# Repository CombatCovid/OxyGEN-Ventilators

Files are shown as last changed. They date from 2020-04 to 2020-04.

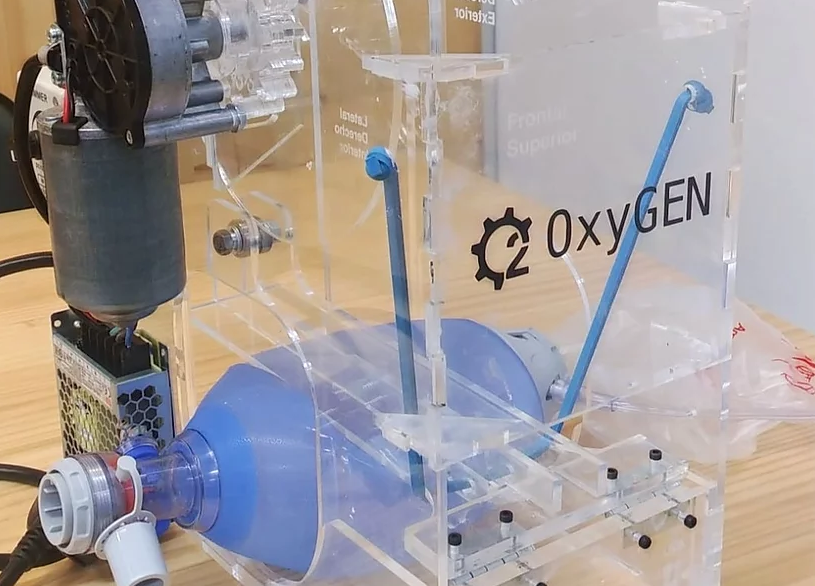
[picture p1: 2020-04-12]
summary.png

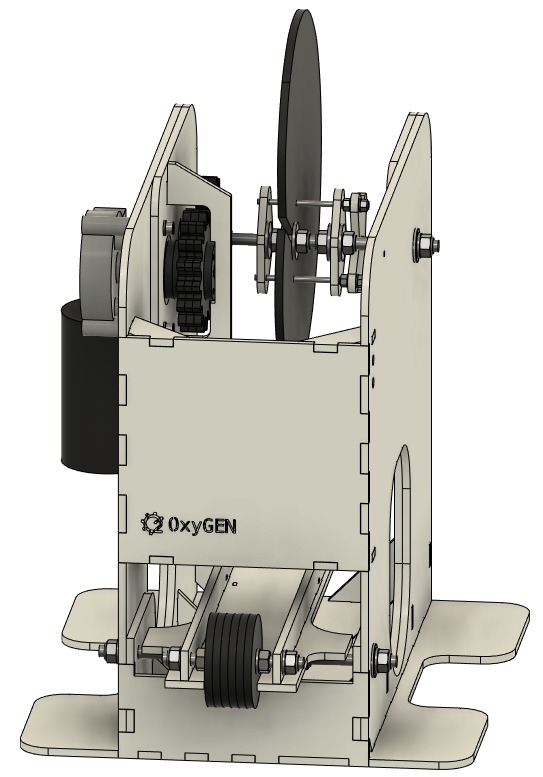
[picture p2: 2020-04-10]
docs/img/5 mm/4b5abb1e-1ea3-4c3a-8013-bc336fb86296.jpeg

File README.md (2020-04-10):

---
title: Title of the project
description: > 
    Put here a description of what the hardware does
keywords:
  - covid-19
  - medical equipment
project-link: https://e-vent.mit.edu/
made: true
made-independently: false
license:
  hardware: Put the license
okh-manifest-version: 1.0.0
date-updated: yyyy-mm-dd
manifest-author:
  name: author
  affiliation: MIT
contributors:
  - A name
  - Another name
sub-parts:
  - undefined
  - undefined
---
# Steps to start documenting the equipment/design you found and chose 
[See this documentation example](https://github.com/CombatCovid/medical-shields-for-3d-printing). You can also download it to see the final result.
1. Download or clone this template to start documenting easily
2. Fill in the source files like STLS, CAD, etc inside

3. Use this one template to create new designs documentation
- Inside docs write down a simple README in language of choice.
- Put in the README.md the reference whre you got the source from to follow up.
- Write down steps to replicate if necessesary as well as guides in sequence.
If this part becomes difficult ask for help here in the [`#how-to-document-designs` channel ](https://discord.gg/QrAyWF)

# Pasos para comenzar a documentar el equipo / diseño que encontró y eligió
[Vea este ejemplo de documentación](https://github.com/CombatCovid/medical-shields-for-3d-printing). Puede tambien descargar este ejemplo.
1. Descargue o clone esta plantilla para comenzar a documentar fácilmente
2. Complete los archivos de origen como STLS, CAD, etc. dentro

3. Utilice esta plantilla para crear documentación de nuevos diseños.
- Los documentos internos escriben un archivo README simple en el idioma de su elección.
- Ponga en README.md la referencia de donde obtuvo la fuente para hacer el seguimiento.
- Escriba los pasos para replicar si es necesario, así como las guías en secuencia.
Si esta parte se vuelve difícil, solicite ayuda aquí en el canal [`# how-to-document-designs`] (https://discord.gg/QrAyWF)

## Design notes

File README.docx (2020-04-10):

title: Emergency ventilator for COVID-19 crisis: OxyGEN-M

description: >

OxyGEN is an emergency device designed to be built by anyone around the world. However, at planetary scales, the availability of tools, materials and industrial facilities varies from place to place.

There are 2 different versions of OxyGEN. The maker version "OxyGEN-M"

and the industrial version "OxyGEN-IP".

OxyGEN-M is designed for makers and can be built using common tools and no special machinery or materials are needed.

keywords:

- covid-19

- medical equipment

- emergency ventilator

- OxyGEN

project-link: https://www.oxygen.protofy.xyz/

made: true

made-independently: false

license:

hardware: Put the license

okh-manifest-version: 1.0.0

date-updated: 2020-04-08

manifest-author:

name: Ramon Turró

affiliation: Protofy.xyz

contributors:

- undefined

sub-parts:

- undefined

- undefined

Location:

Barcelona

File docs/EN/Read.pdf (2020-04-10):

OxyGEN is an emergency device for the COVID-19 health crisis. OxyGEN is an open hardware prototype that has been collaboratively developed by a group of engineers led by Barcelona based company, PROTOFY.xyz. Initiated March 2020.
Web: https://www.oxygen.protofy.xyz/

The files that you’ll find inside this folder are to make the wooden version of the device when you don't have a laser or Cnc, although the plans also include a Dxf file to be used in a Cnc.
I’ve used hard birch plywood, although the best option is to use a hypoallergenic material such as methacrylate or Pvc. You could also use chipboard or Mdf with melamine on both sides, or varnishing the wood. You should use hard plywood or hard wood to make the gears.
If you install an electronic speed control, you can avoid doing the gears. You can also modify the ratio between the gears to adapt them to the revolutions of your Wiper Motor.

If you have any questions please contact me by email: info@paoson.com

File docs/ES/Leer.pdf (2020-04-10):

OxyGEN es un dispositivo de emergencia para la crisis sanitaria del COVID-19, Se trata de un prototipo de hardware abierto desarrollado por un grupo de ingenieros liderado por la empresa Barcelonesa Protofy.xyz. iniciado en Marzo 2020.
Web: https://www.oxygen.protofy.xyz/?lang=es

Los documentos que encontrarás en esta carpeta son los archivos para poder fabricar la version en madera del dispositivo. La idea es poder fabricar el dispositivo con herramienta manuales, sin una laser o Cnc, aunque los planos incluyen archivos Dxf para poder usar en un pantógrafo.
Aunque he usado contrachapado duro de abedul, lo ideal sería usar un material antiséptico y no madera, como metacrilato o Pvc. Como opción se podría usar tablero aglomerado o Mdf con melamina por ambas caras y cantear, o barnizar la madera. Los engranajes siempre con contrachapado duro o madera dura.
El motor podría ir directo y evitar los engranajes si se regula la velocidad de giro de forma electronica. También se puede modificar el ratio entre los engranajes para adaptarlos a las revoluciones de tu motor.

Si tienes alguna duda puedes contactarme por email: info@paoson.com

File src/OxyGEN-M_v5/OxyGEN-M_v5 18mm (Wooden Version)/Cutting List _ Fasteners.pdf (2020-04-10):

# Cutting List / Fasteners

Lateral Side 1 | 353 x 340 x 18mm | 18mm Hard Plywood
Lateral Side 2 | 353 x 340 x 18mm | 18mm Hard Plywood
Base | 340 x 142 x 18mm | 18mm Hard Plywood
Base Planca | 393 x 84 x 18mm | 18mm Hard Plywood
Lateral Palanca - | 293 x 52 x 18mm(x2) | 18mm Hard Plywood
Trasera Back 1 | 142x 35 x 18mm | 18mm Hard Plywood
Trasera Back 2 | 150 x 142 x 18mm | 18mm Hard Plywood
Sujeta Leva 1 | 70 x 50 x 18mm | 18mm Hard Plywood
Sujeta Leva 2 | 70 x 50 x 18mm | 18mm Hard Plywood
Engranaje Gear | 100 x 100 x 18mm | 18mm Hard Plywood
Engranaje Motor Gear | 100 x 100 x 18mm | 18mm Hard Plywood
Engranaje Motor Gear 2 | 37 x 37 x 18mm | 18mm Hard Plywood
Ejes | 50 x 25 x 18mm(x2) | 18mm Hard Plywood
Cam Leva 1 | 220 x 210 x 9mm | 9mm Hard Plywood
Cam Leva 1 | 250 x 230 x 9mm | 9mm Hard Plywood
Cam Leva 1 | 270 x 245 x 9mm | 9mm Hard Plywood
Cam Leva 1 | 300 x 270 x 9mm | 9mm Hard Plywood

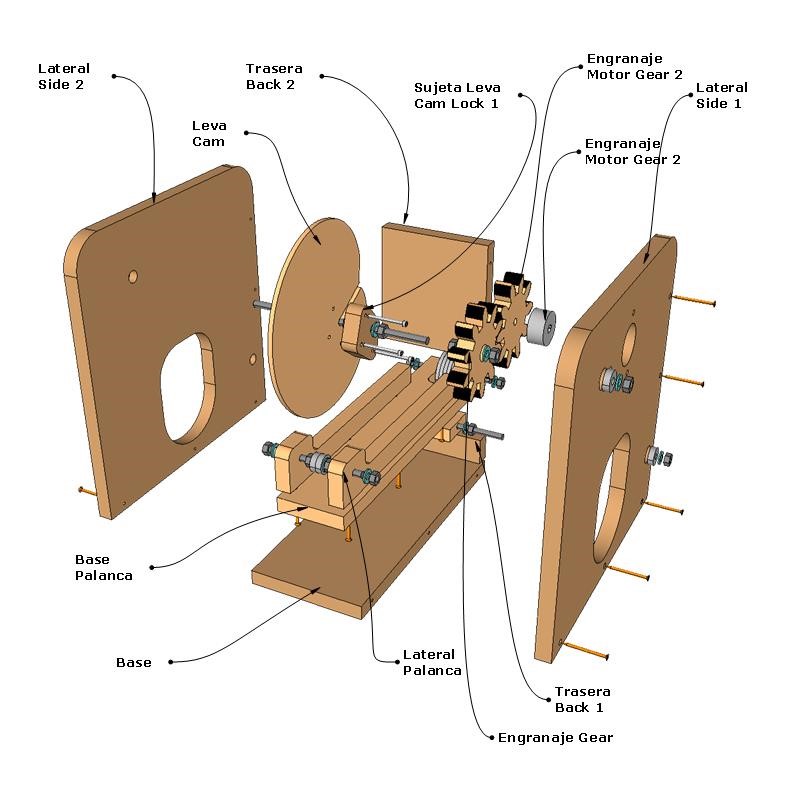
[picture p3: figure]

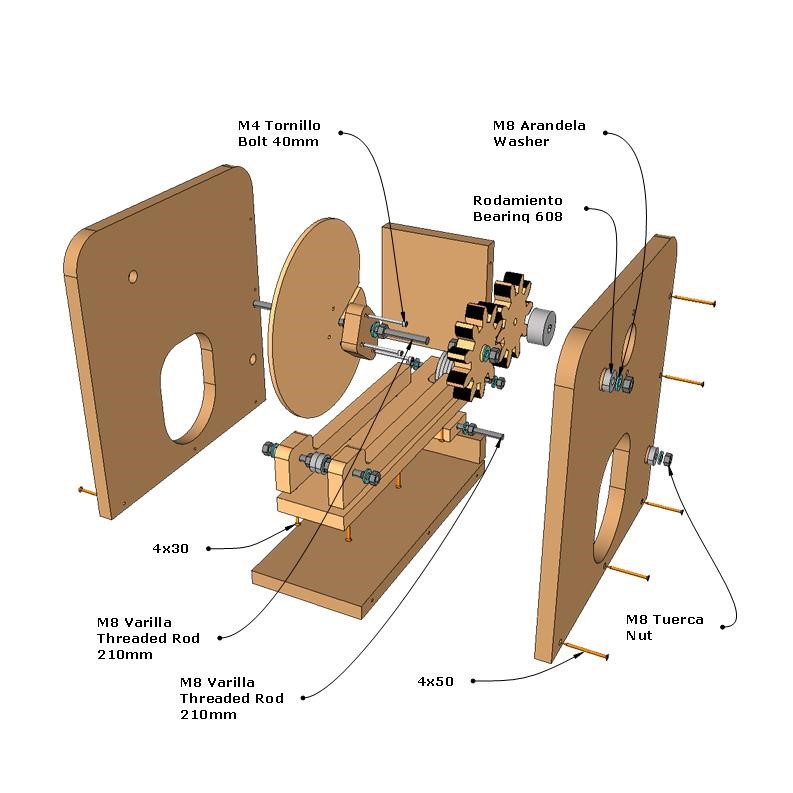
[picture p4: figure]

Allen Socket Head Screw: (https://www.paoson.com/forum/viewtopic.php?f=22&t=137)
3x M4 40mm

Threaded Rod/Varilla Roscada: (https://www.paoson.com/forum/viewtopic.php?f=22&t=892)
2x M8 210mm

Loking Nuts/Tuercas Autoblocantes: (https://www.paoson.com/forum/viewtopic.php?f=22&t=137) 16x M8

Washers / Arandelas: (https://www.paoson.com/forum/viewtopic.php?f=22&t=137)
16x M8 16mm Outer Diameter

Wood Screw: (https://www.paoson.com/forum/viewtopic.php?f=22&t=137)
10x 4x30
12x 4x50

1x Wiper Motor / Motor Limpiaparabrisas 6x 608 Bearings /Rodamientos

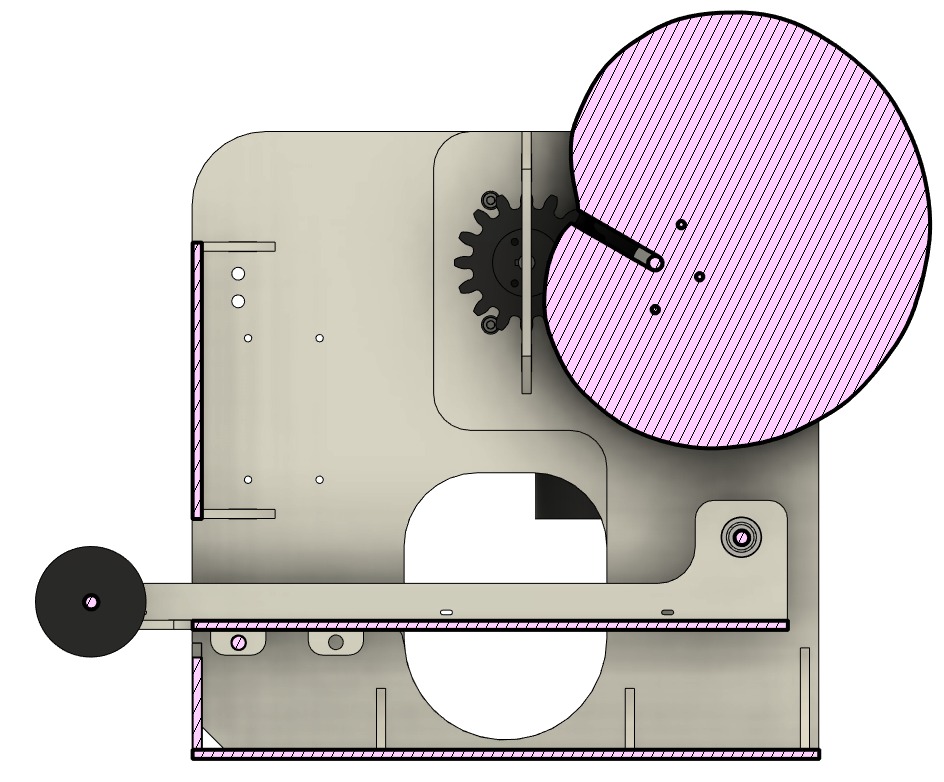
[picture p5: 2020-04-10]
docs/img/5 mm/60694f12-7864-42e0-a22d-a7ac66c59804.jpeg

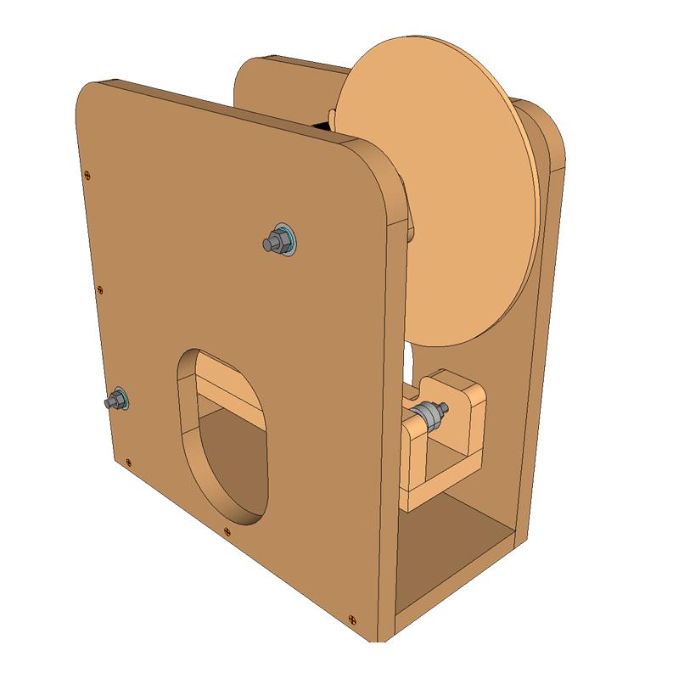
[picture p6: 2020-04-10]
docs/img/18mm/OxyGEN-master_Madera_Photo 1.jpg

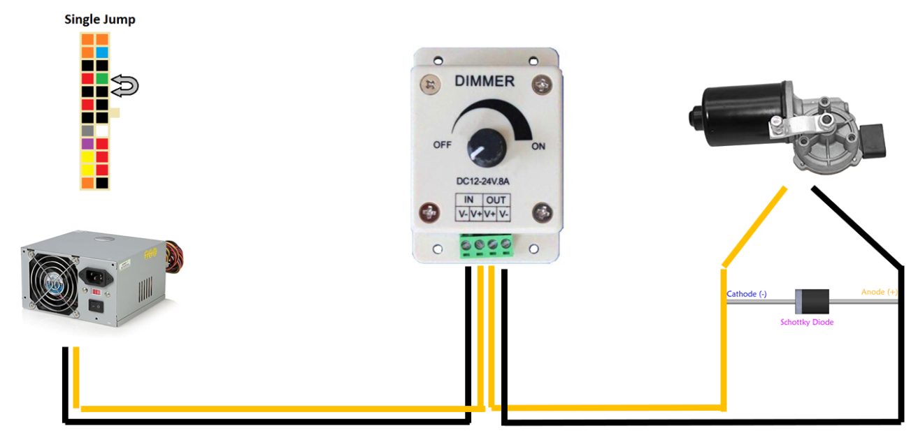
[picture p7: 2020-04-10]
docs/img/18mm/Electric_Diagram.png

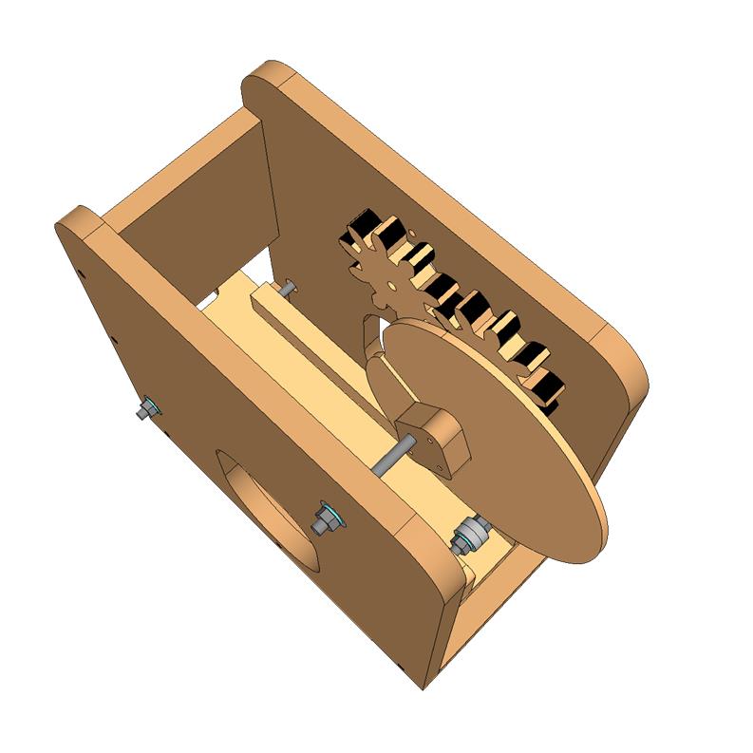
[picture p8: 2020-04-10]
docs/img/18mm/OxyGEN-master_Madera_Photo 2.jpg

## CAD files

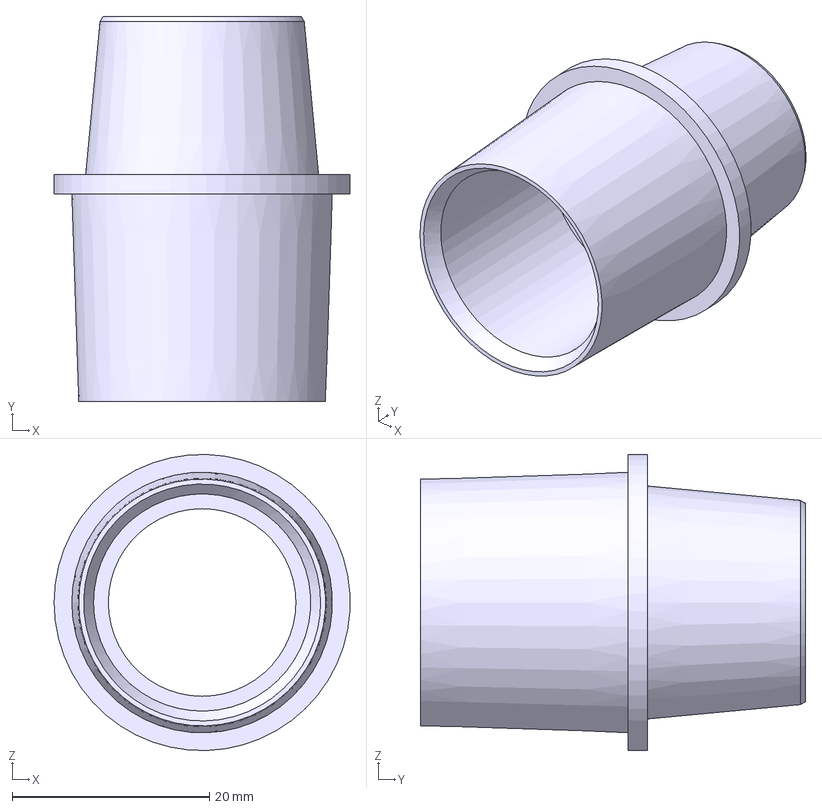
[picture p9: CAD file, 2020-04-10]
src/accessories/tube to spur valve.step
30.0 x 39.0 x 30.0 mm

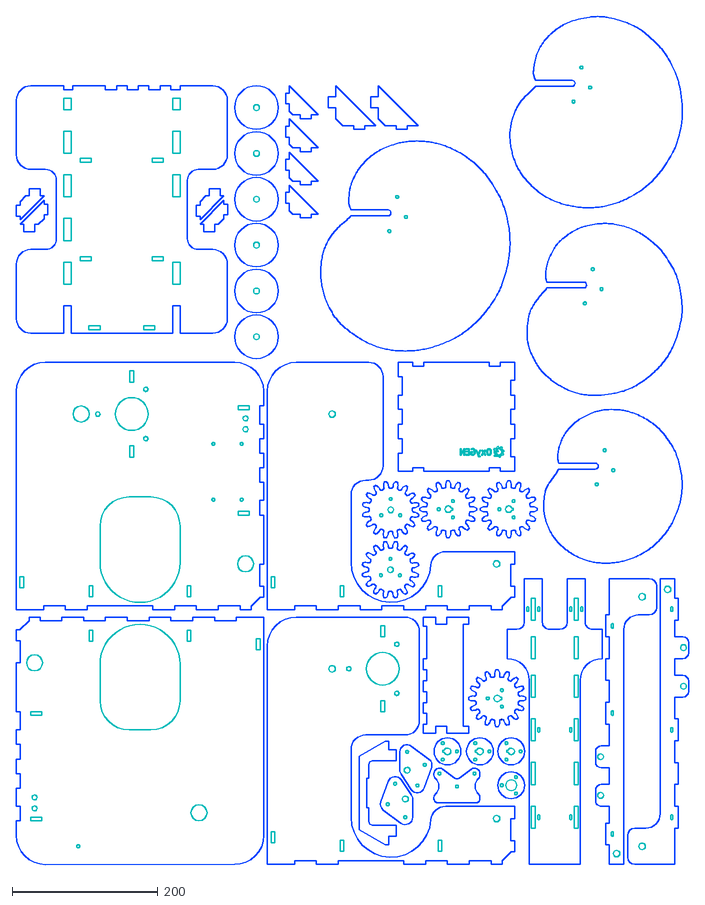
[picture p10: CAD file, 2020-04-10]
src/OxyGEN-M_v5/OxyGEN-M_v5 5mm/DXF/OxyGEN_Maker_V5.dxf
924.0 x 1165.5

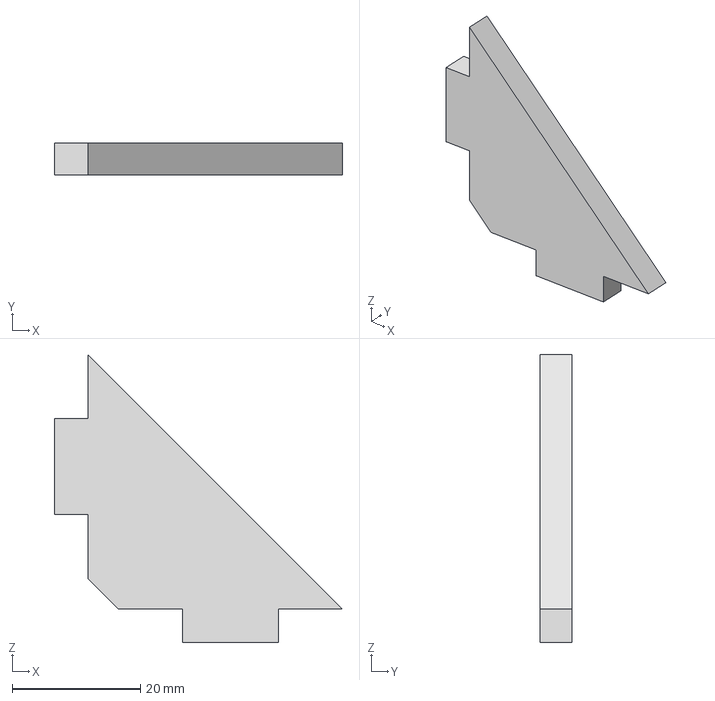
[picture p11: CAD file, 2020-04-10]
src/OxyGEN-M_v5/OxyGEN-M_v5 5mm/STEP/Oxygen Maker Escuadra Frontal 2.step
45.0 x 5.00 x 45.0 mm

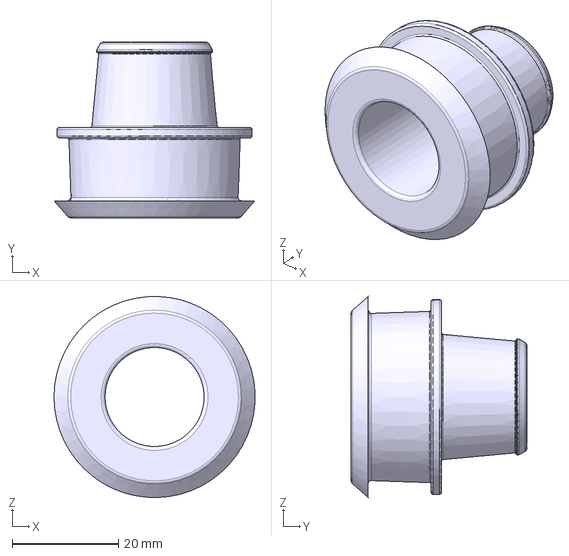
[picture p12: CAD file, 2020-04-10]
src/accessories/spur back to tube.step
37.8 x 33.0 x 37.8 mm

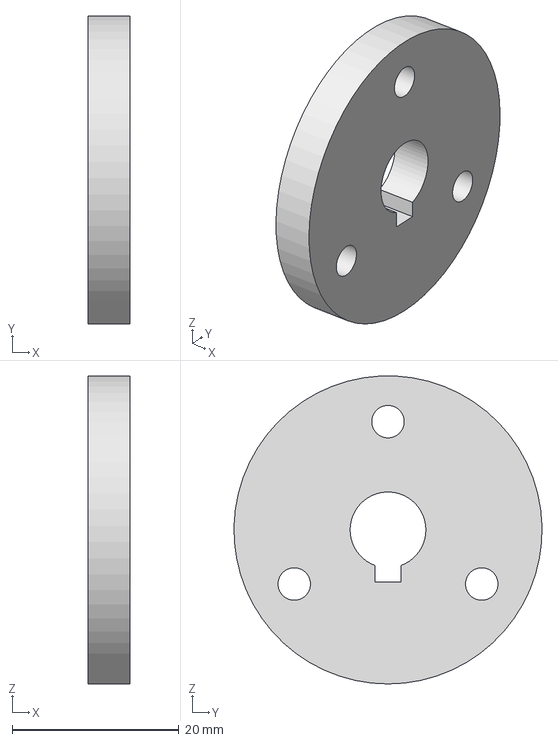
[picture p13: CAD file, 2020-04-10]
src/OxyGEN-M_v5/OxyGEN-M_v5 5mm/STEP/Oxygen Maker Coupling 3.step
5.00 x 37.0 x 37.0 mm

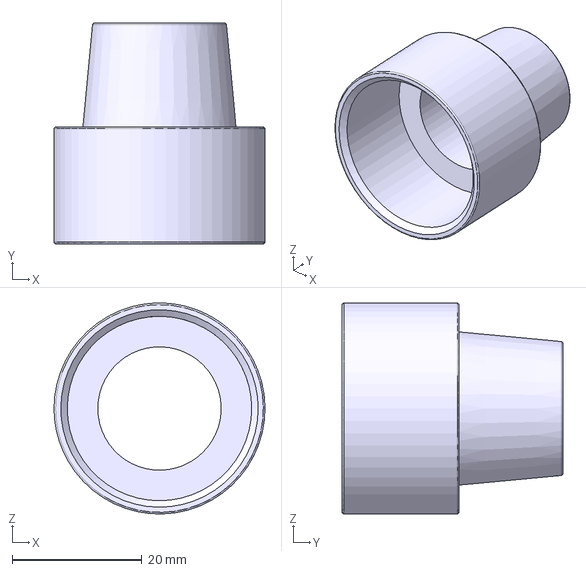
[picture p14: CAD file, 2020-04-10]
src/accessories/Tube to oval valve.step
32.5 x 34.0 x 32.5 mm

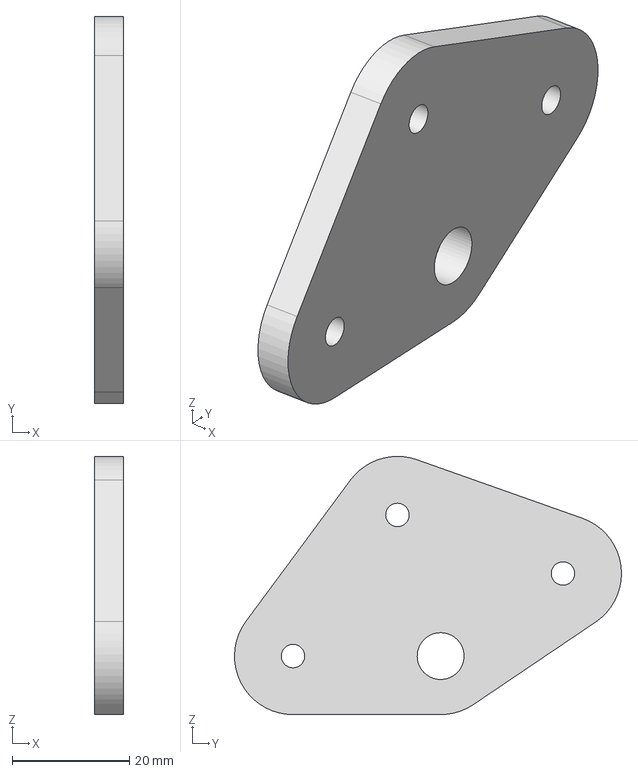
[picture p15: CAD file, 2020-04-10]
src/OxyGEN-M_v5/OxyGEN-M_v5 5mm/STEP/Oxygen Maker Soporte Pasador 1.step
5.00 x 66.1 x 44.1 mm

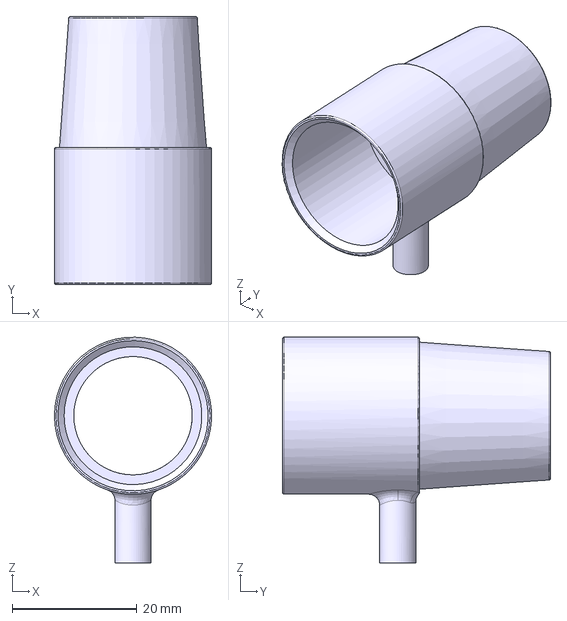
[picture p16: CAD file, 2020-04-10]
src/accessories/tube manometer tube .step
25.2 x 43.0 x 36.2 mm

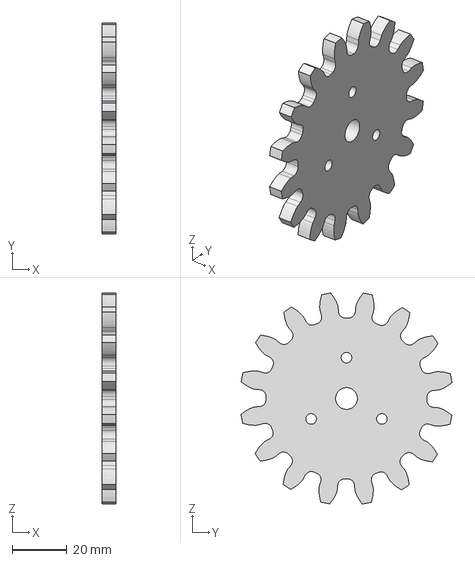
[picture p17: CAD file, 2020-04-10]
src/OxyGEN-M_v5/OxyGEN-M_v5 5mm/STEP/Oxygen Maker Engranaje 1.step
5.00 x 77.4 x 77.4 mm

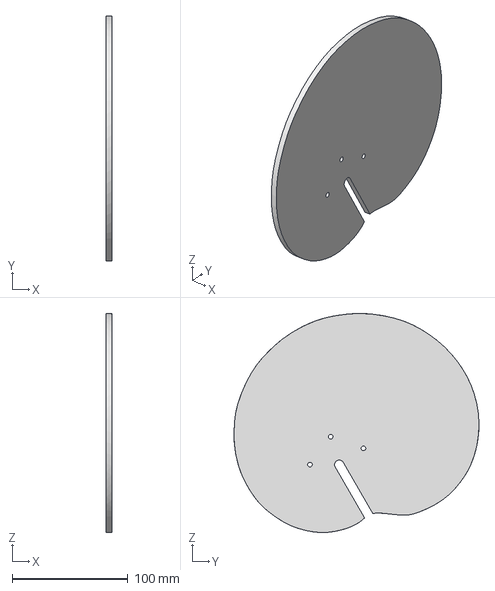
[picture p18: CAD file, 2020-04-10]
src/OxyGEN-M_v5/OxyGEN-M_v5 5mm/STEP/Oxygen Maker Leva4 Entallada.step
5.00 x 211.2 x 188.9 mm

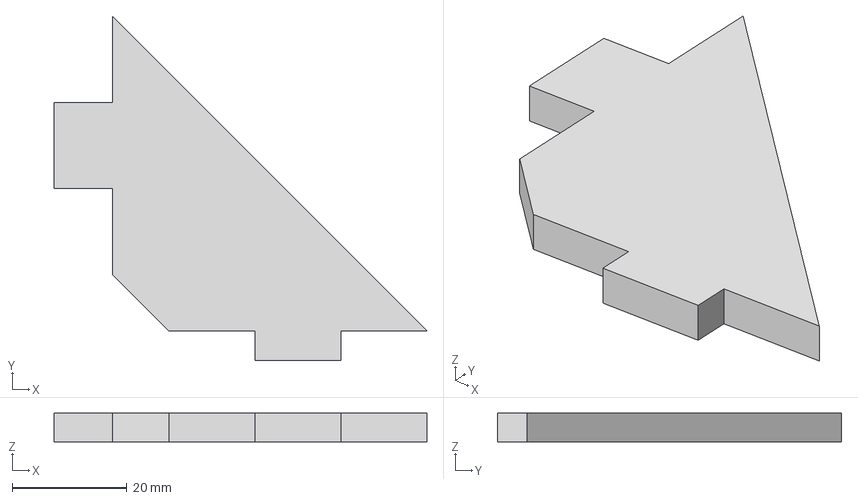
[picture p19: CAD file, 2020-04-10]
src/OxyGEN-M_v5/OxyGEN-M_v5 5mm/STEP/Oxygen Maker Escuadra Trasera 1.step
65.0 x 60.0 x 5.00 mm

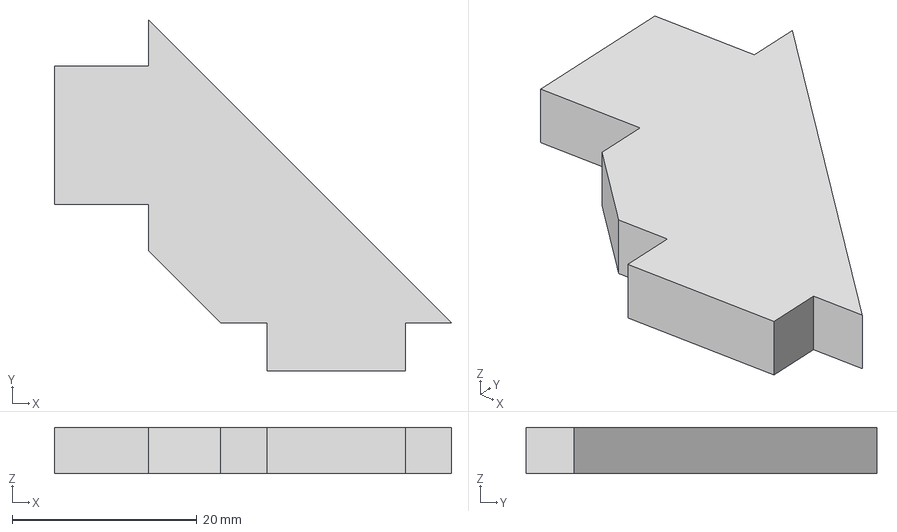
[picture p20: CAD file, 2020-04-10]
src/OxyGEN-M_v5/OxyGEN-M_v5 5mm/STEP/Oxygen Maker Escuadra Base 3.step
43.0 x 38.0 x 5.00 mm

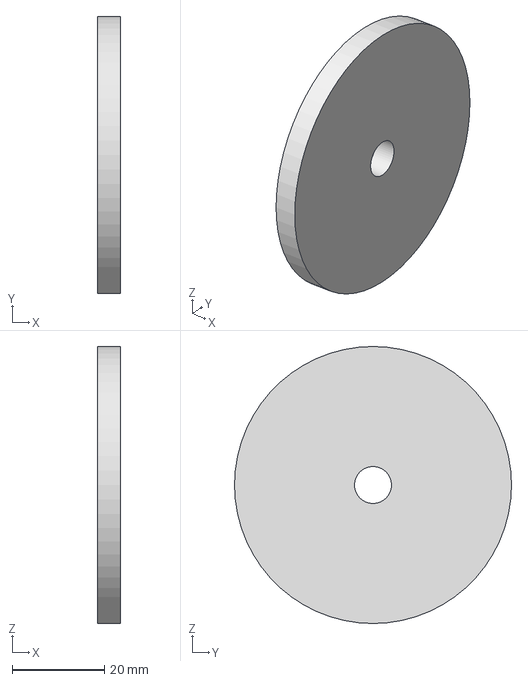
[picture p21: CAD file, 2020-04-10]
src/OxyGEN-M_v5/OxyGEN-M_v5 5mm/STEP/Oxygen Maker Contrapeso 1.step
5.00 x 60.0 x 60.0 mm

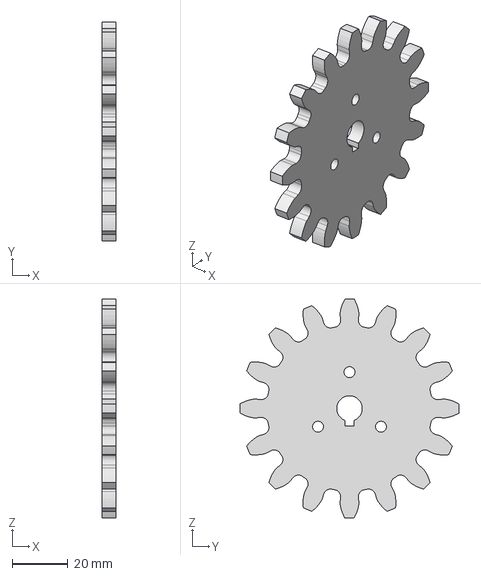
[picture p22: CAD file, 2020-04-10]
src/OxyGEN-M_v5/OxyGEN-M_v5 5mm/STEP/Oxygen Maker Coupling Dentado 2.step
5.00 x 78.3 x 78.3 mm

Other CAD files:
src/OxyGEN-M_v5/OxyGEN-M_v5 5mm/STEP/Oxygen Maker Coupling 2.step
src/OxyGEN-M_v5/OxyGEN-M_v5 5mm/STEP/Oxygen Maker Escuadra Frontal 1.step
src/OxyGEN-M_v5/OxyGEN-M_v5 5mm/STEP/Oxygen Maker Leva2 Entallada.step
src/OxyGEN-M_v5/OxyGEN-M_v5 5mm/STEP/Oxygen Maker Contrapeso 4.step
src/OxyGEN-M_v1/Oxygen DXF/Oxygen DXF Base (Madera 20mm).dxf
src/OxyGEN-M_v1/Oxygen DXF/Oxygen DXF Coupling (Madera 20mm).dxf
src/OxyGEN-M_v1/Oxygen DXF/Oxygen DXF Lateral Derecho (Madera 20mm).dxf
src/OxyGEN-M_v1/Oxygen DXF/Oxygen DXF Lateral Izquierdo (Madera 20mm).dxf
src/OxyGEN-M_v1/Oxygen DXF/Oxygen DXF Leva (Madera 20mm).dxf
src/OxyGEN-M_v1/Oxygen DXF/Oxygen DXF Plancha Frontal (Madera 20mm).dxf
src/OxyGEN-M_v1/Oxygen DXF/Oxygen DXF Plancha Superior (Madera 20mm).dxf
src/OxyGEN-M_v1/Oxygen DXF/Oxygen DXF Rueda Grande (Madera 20mm).dxf
src/OxyGEN-M_v1/Oxygen DXF/Oxygen DXF Rueda Pequeña (Madera 20mm).dxf
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

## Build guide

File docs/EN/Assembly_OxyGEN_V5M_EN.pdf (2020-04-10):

Step 1: Assembling the sides.

Both pieces that form each of the sides are adhered together with the corresponding brackets as shown in the image below. The side where the motor is installed will have the 3 fixing holes, which will coincide once the two pieces that make up the side come together. The brackets will serve as guides so that the pieces coincide.

Step 2: Joining the base:

We adhere both pieces to the base and the sides:

Step 3: Assembling mobile arm:
Step 4: Mobile arm assembly

Short screws L = 90 mm

Step 5: Installing the arm to the structure
Step 6: Piece to lock Cam:
L Screws = 70 mm
Step 6: Main Shaft - Shaft Assembly
Step 7: Placement of the shaft and the cam lock
Step 8: Engine mounting:
Step 9: Placing the gear

The motor gear has three serrated layers and 4 other circumferences.

Step 10: Cam Placement

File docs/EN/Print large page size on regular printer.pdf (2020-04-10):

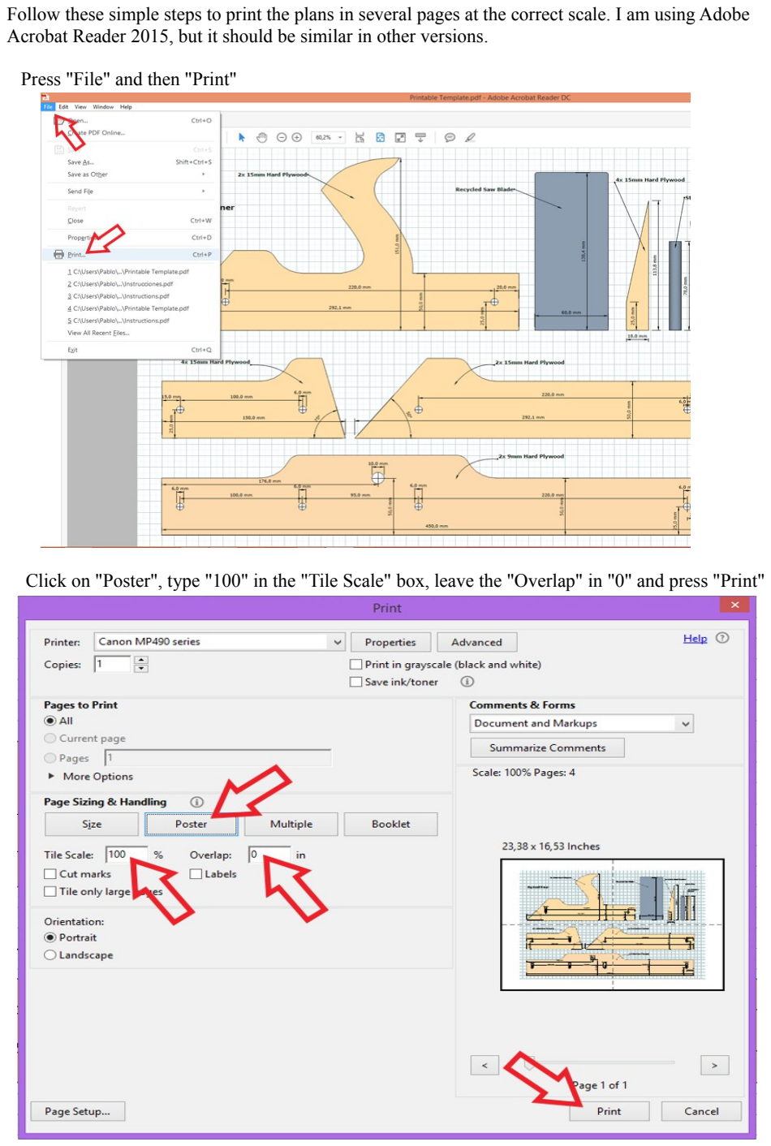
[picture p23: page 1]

Follow these simple steps to print the plans in several pages at the correct scale. I am using Adobe Acrobat Reader 2015, but it should be similar in other versions.

Press "File" and then "Print"

Click on "Poster", type "100" in the "Tile Scale" box, leave the "Overlap" in "0" and press "Print"

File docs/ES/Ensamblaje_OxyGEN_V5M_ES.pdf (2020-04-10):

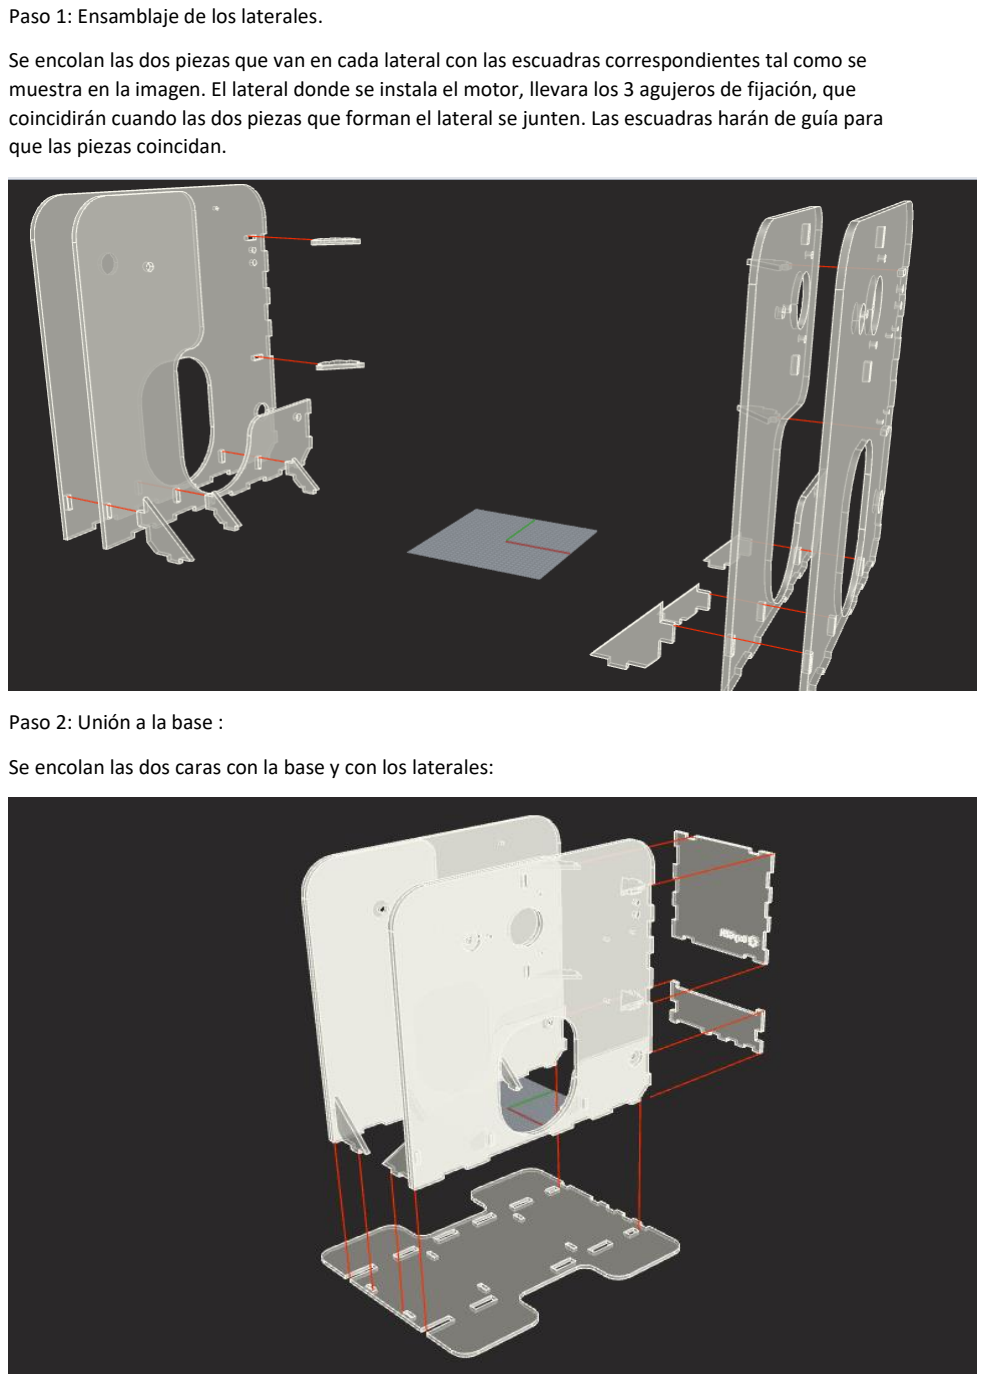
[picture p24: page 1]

Paso 1: Ensamblaje de los laterales.

Se encolan las dos piezas que van en cada lateral con las escuadras correspondientes tal como se muestra en la imagen. El lateral donde se instala el motor, llevara los 3 agujeros de fijación, que coincidirán cuando las dos piezas que forman el lateral se junten. Las escuadras harán de guía para que las piezas coincidan.

Paso 2: Unión a la base :

Se encolan las dos caras con la base y con los laterales:

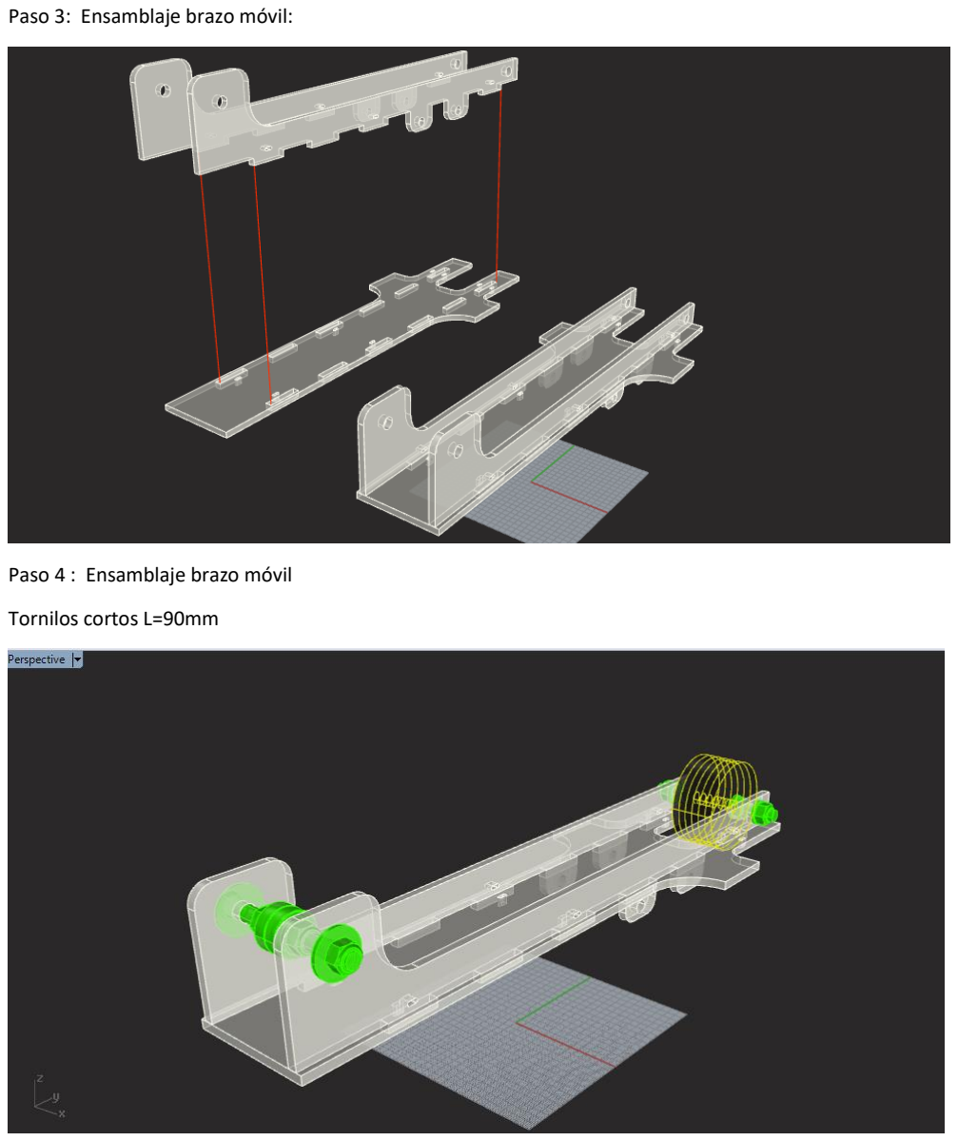
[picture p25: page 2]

Paso 3: Ensamblaje brazo móvil:

Paso 4 : Ensamblaje brazo móvil

Tornilos cortos L=90mm

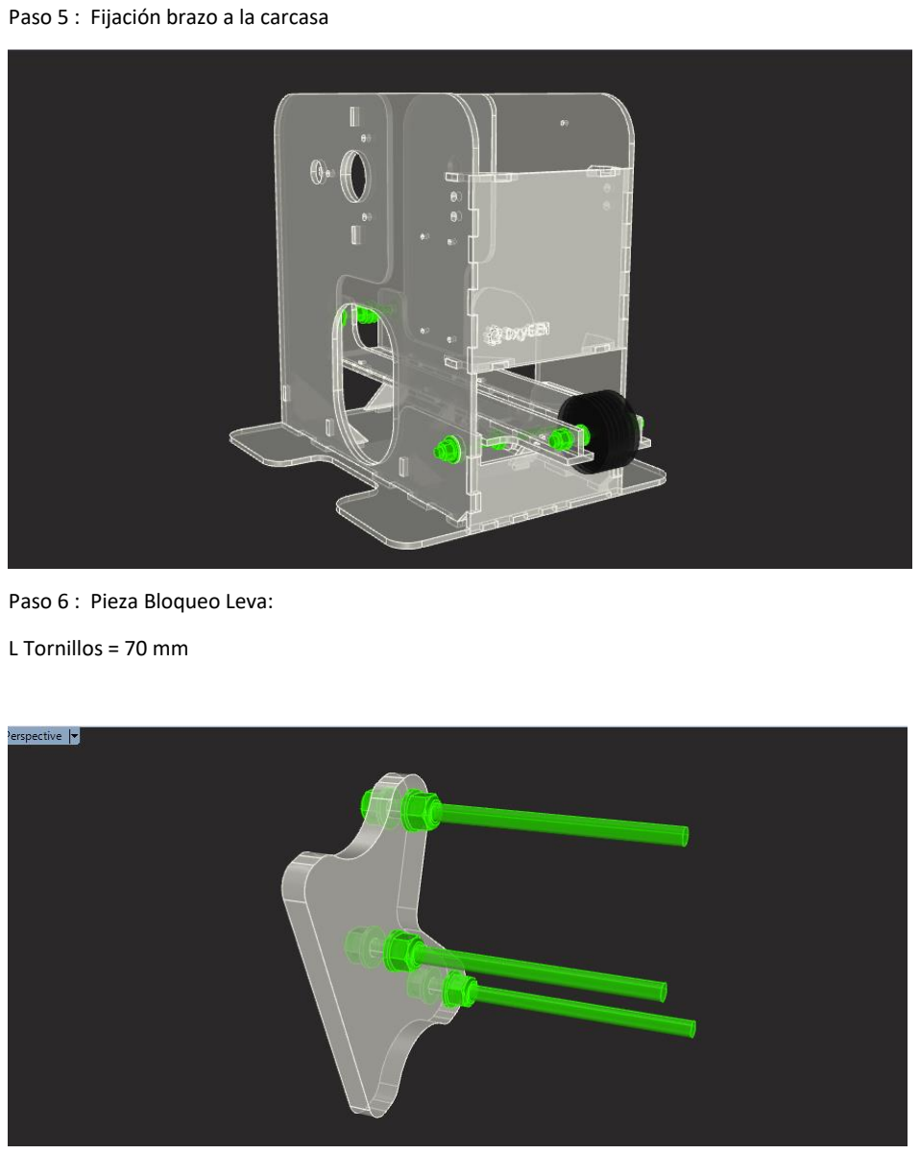
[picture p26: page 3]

Paso 5 : Fijación brazo a la carcasa

Paso 6 : Pieza Bloqueo Leva:

L Tornillos = 70 mm

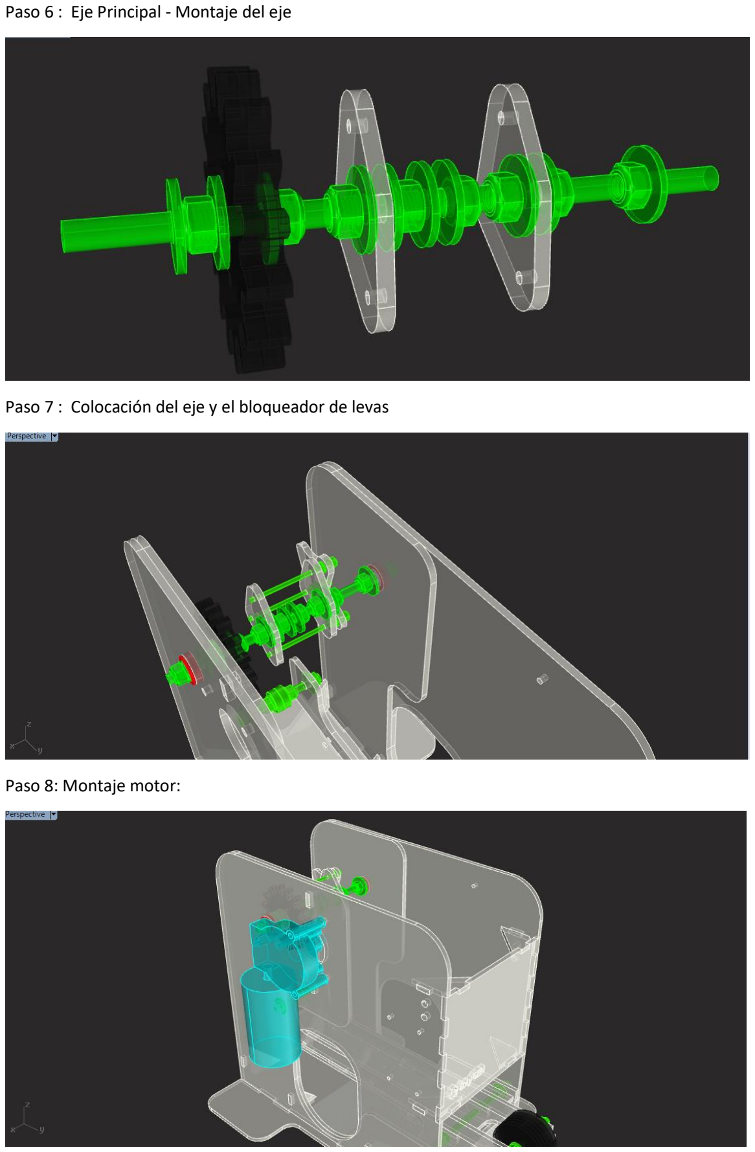
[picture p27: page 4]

Paso 6 : Eje Principal - Montaje del eje

Paso 7 : Colocación del eje y el bloqueador de levas

Paso 8: Montaje motor:

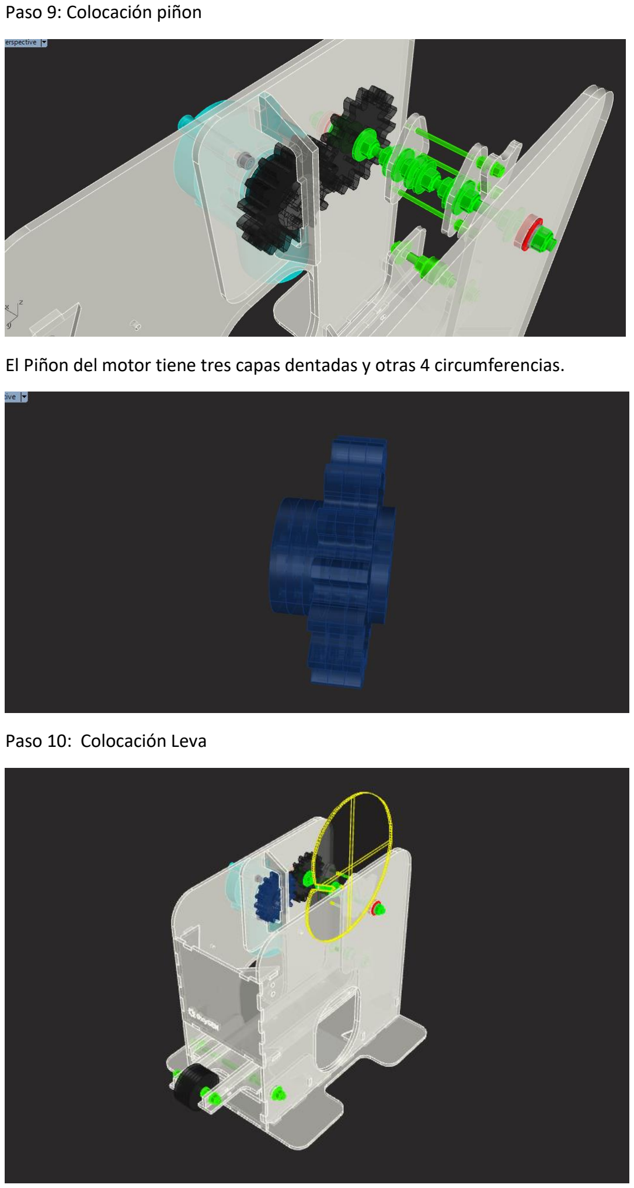
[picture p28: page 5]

Paso 9: Colocación piñon

El Piñon del motor tiene tres capas dentadas y otras 4 circumferencias.

Paso 10: Colocación Leva

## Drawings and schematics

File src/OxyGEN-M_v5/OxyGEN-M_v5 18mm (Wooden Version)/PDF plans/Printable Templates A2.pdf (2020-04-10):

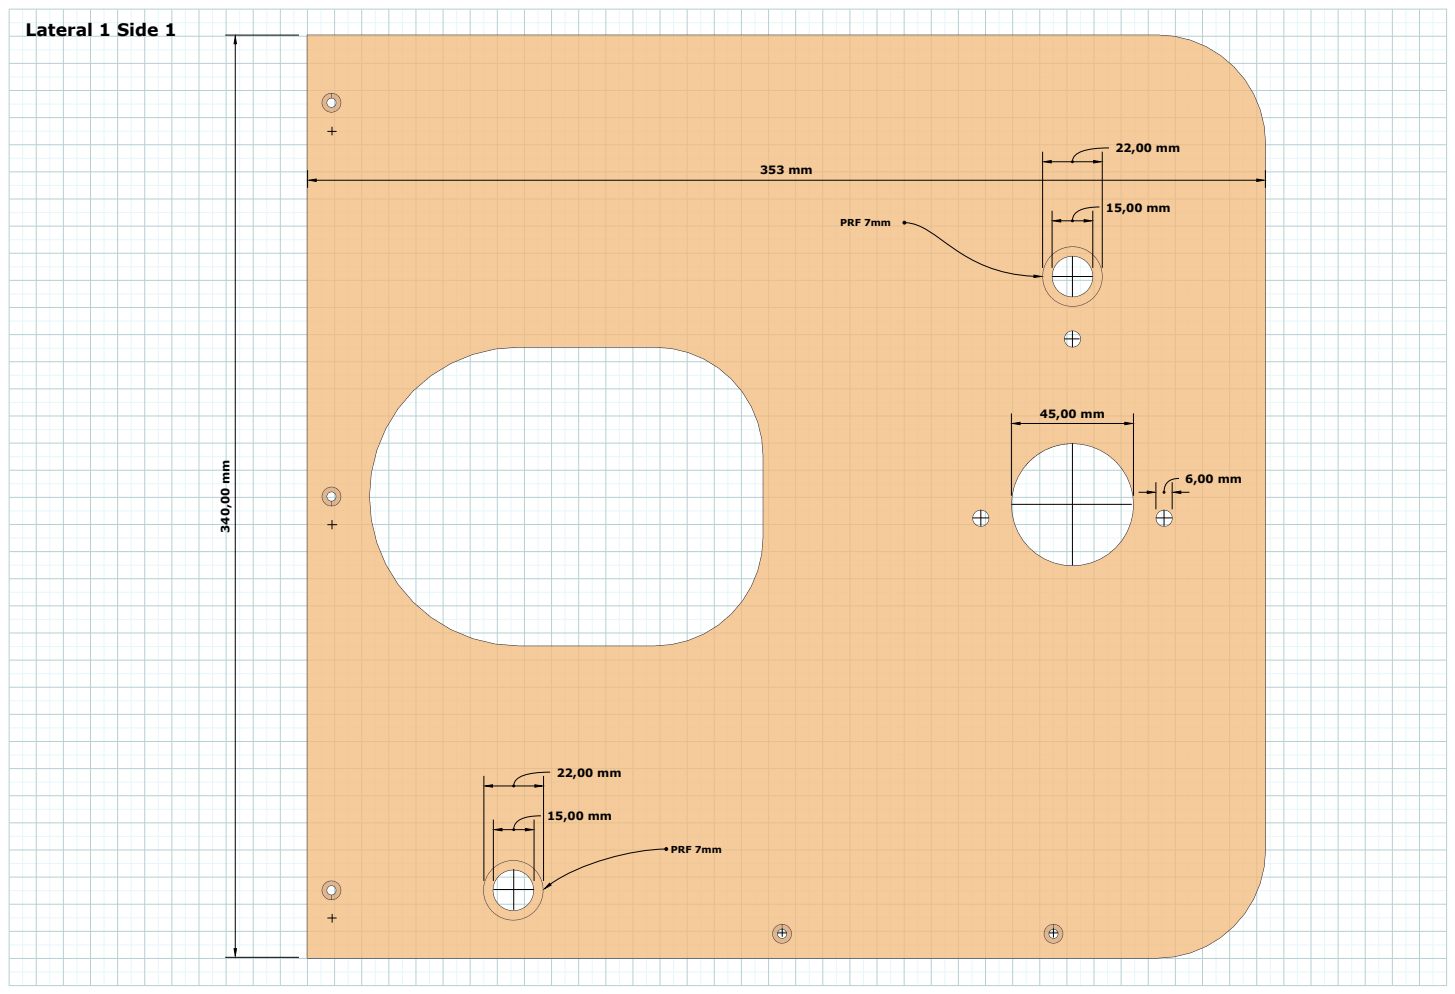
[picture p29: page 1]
PRF 7mm; Lateral 1; Side

PRF | 7mm

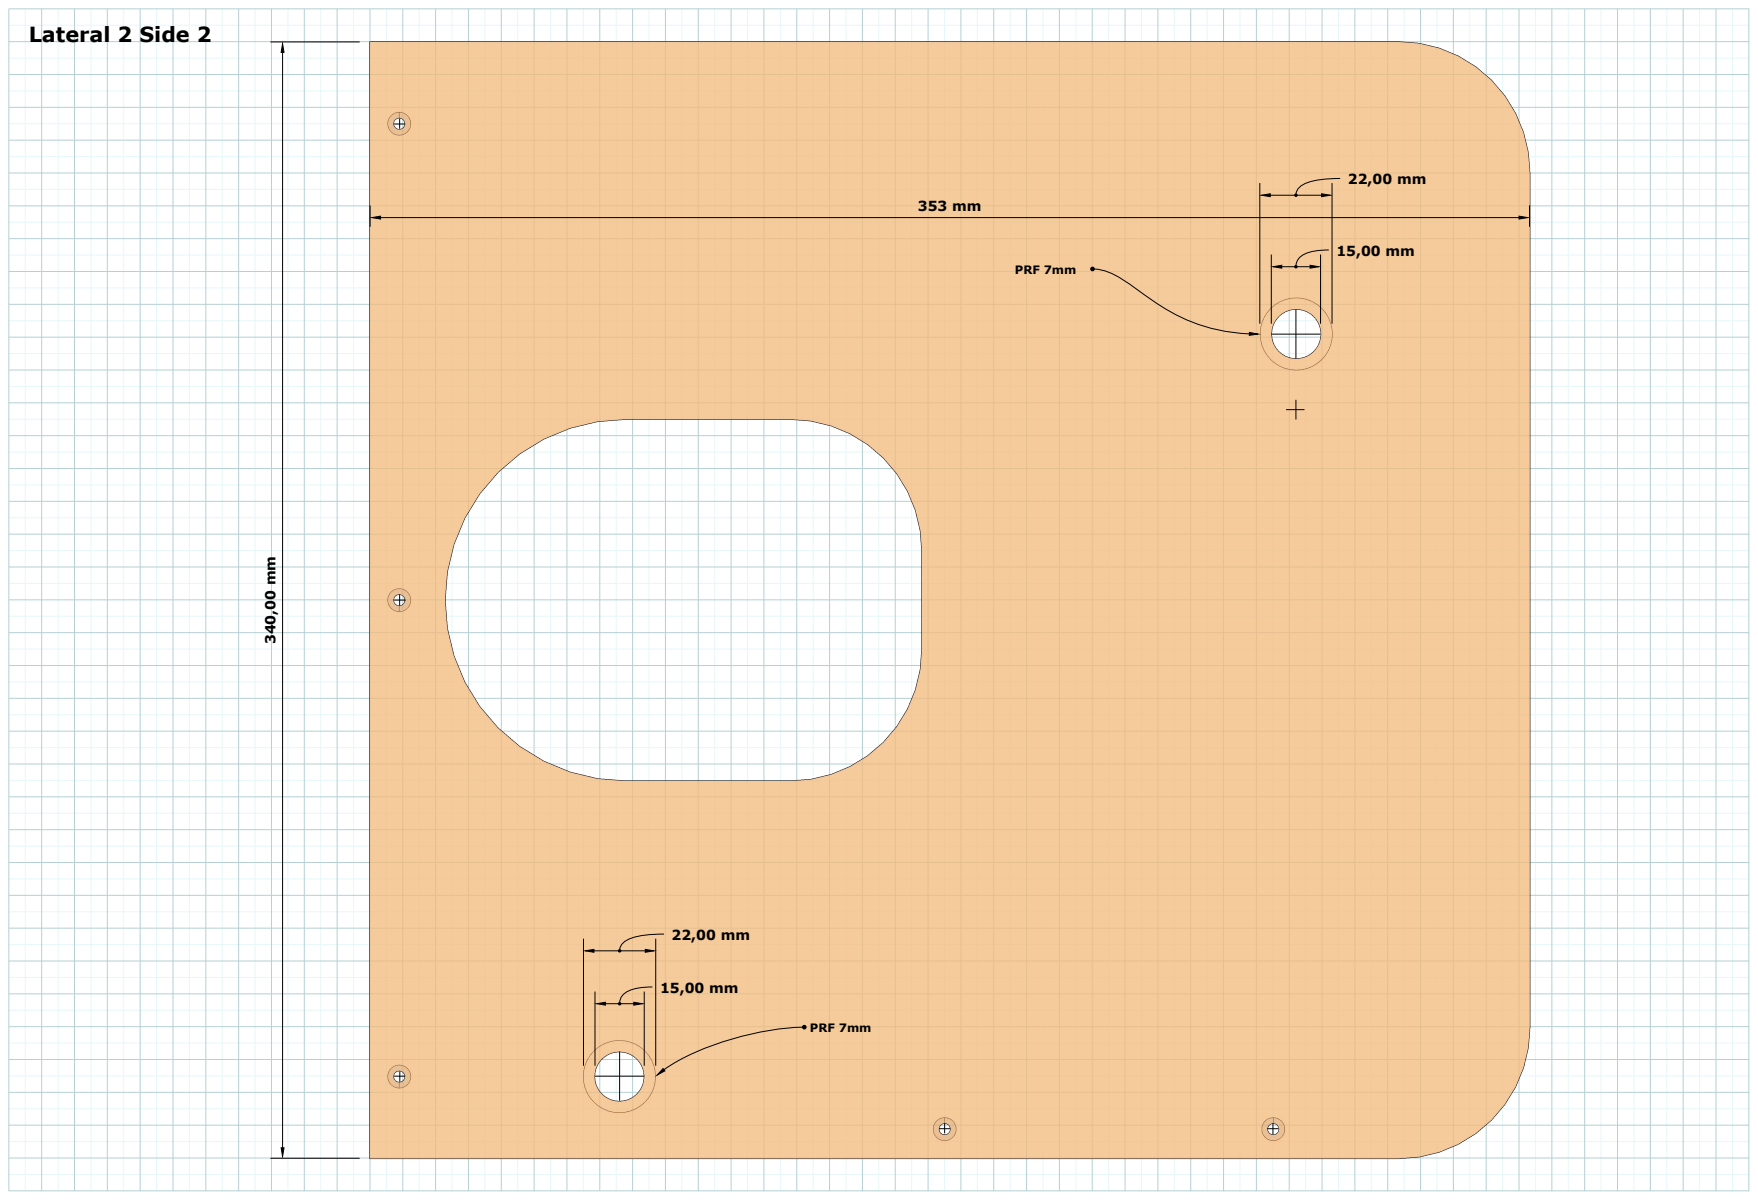
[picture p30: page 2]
Lateral 2; Side; PRF 7mm

PRF | 7mm

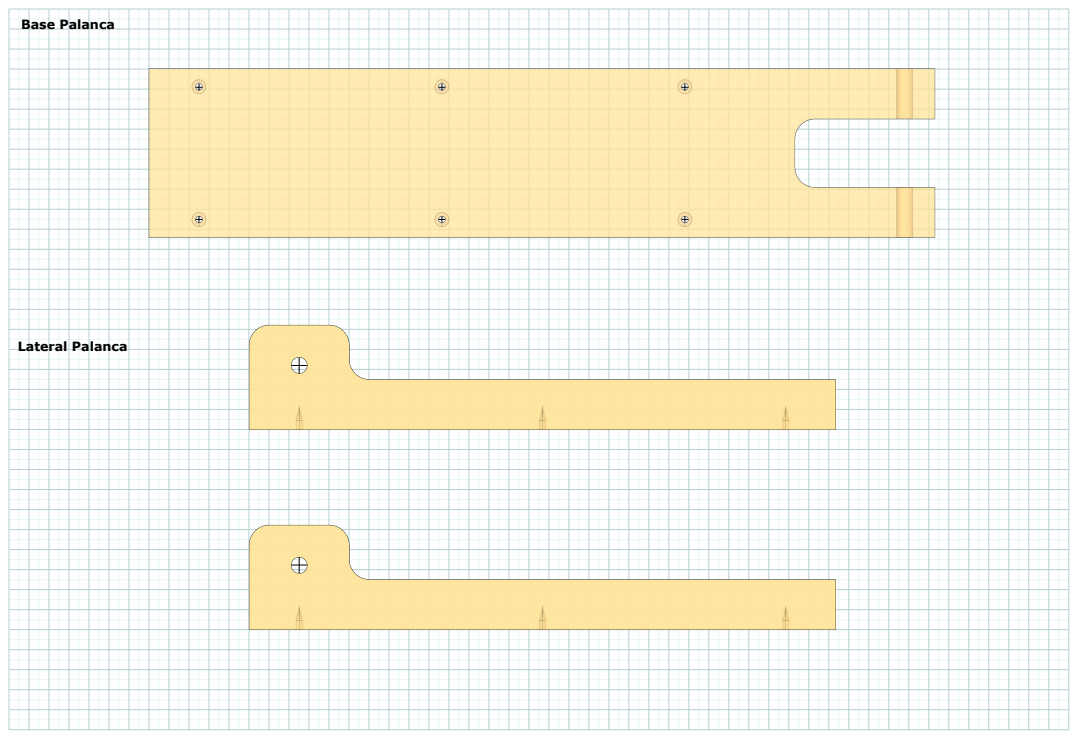
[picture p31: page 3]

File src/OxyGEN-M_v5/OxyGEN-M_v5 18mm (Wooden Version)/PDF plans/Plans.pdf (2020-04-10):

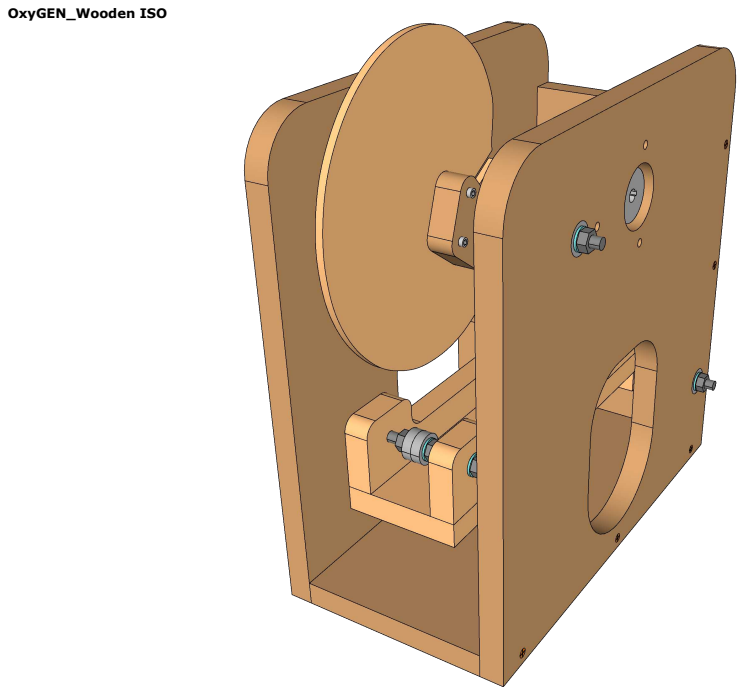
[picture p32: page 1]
OxyGEN_Wooden ISO

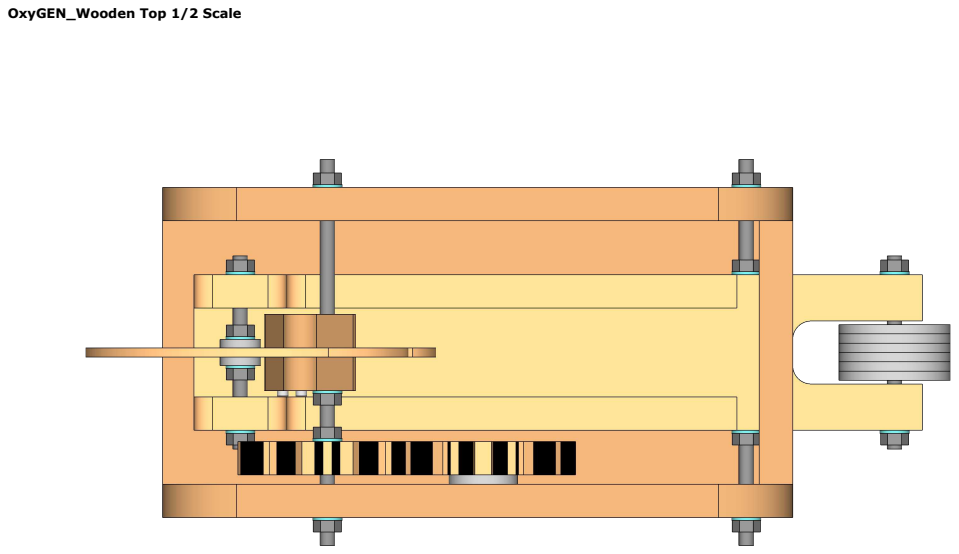
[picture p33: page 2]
OxyGEN_Wooden Top 1/2 Scale

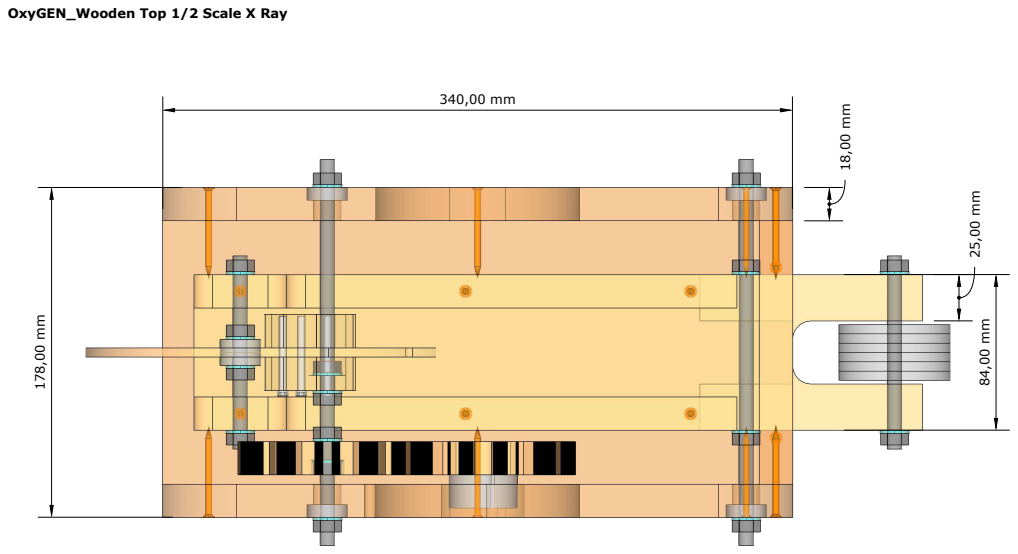
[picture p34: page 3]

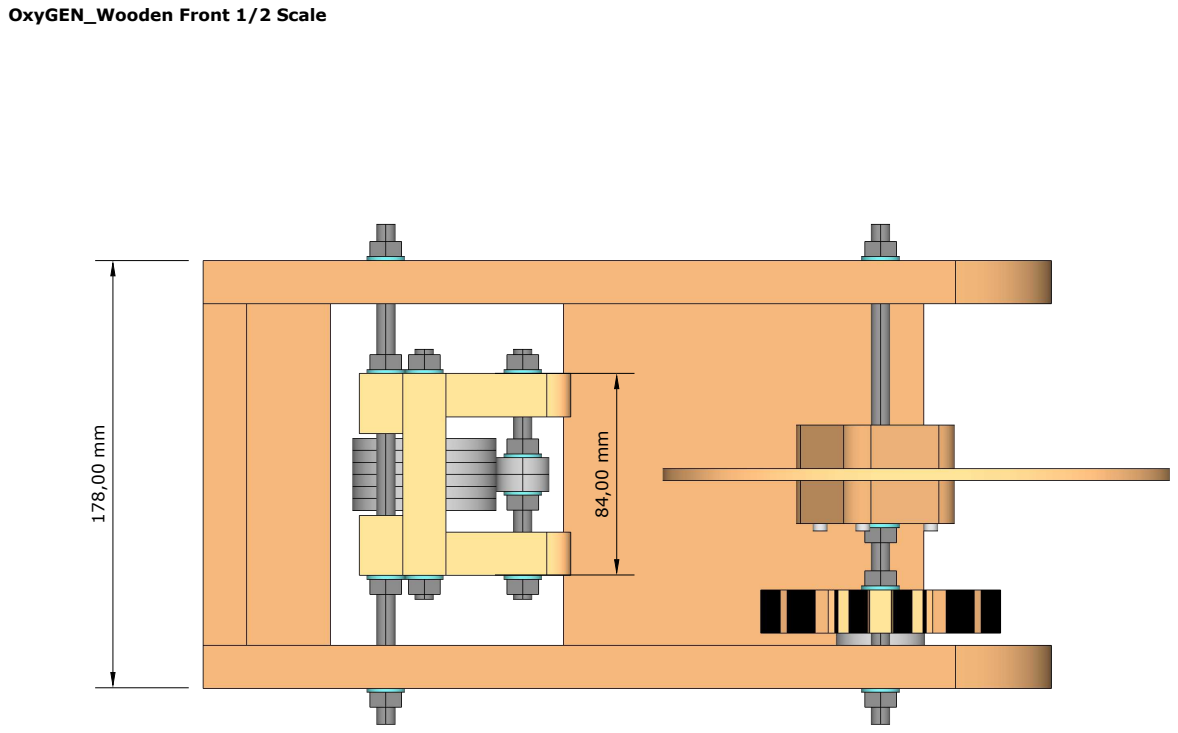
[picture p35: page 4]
OxyGEN_Wooden Front 1/2 Scale

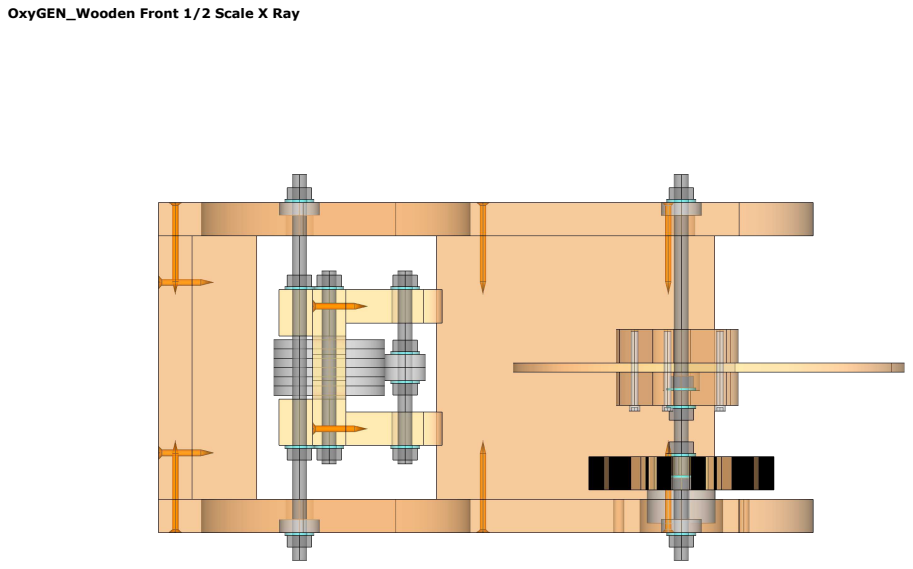
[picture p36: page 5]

OxyGEN_Wooden Front 1/2 Scale X Ray

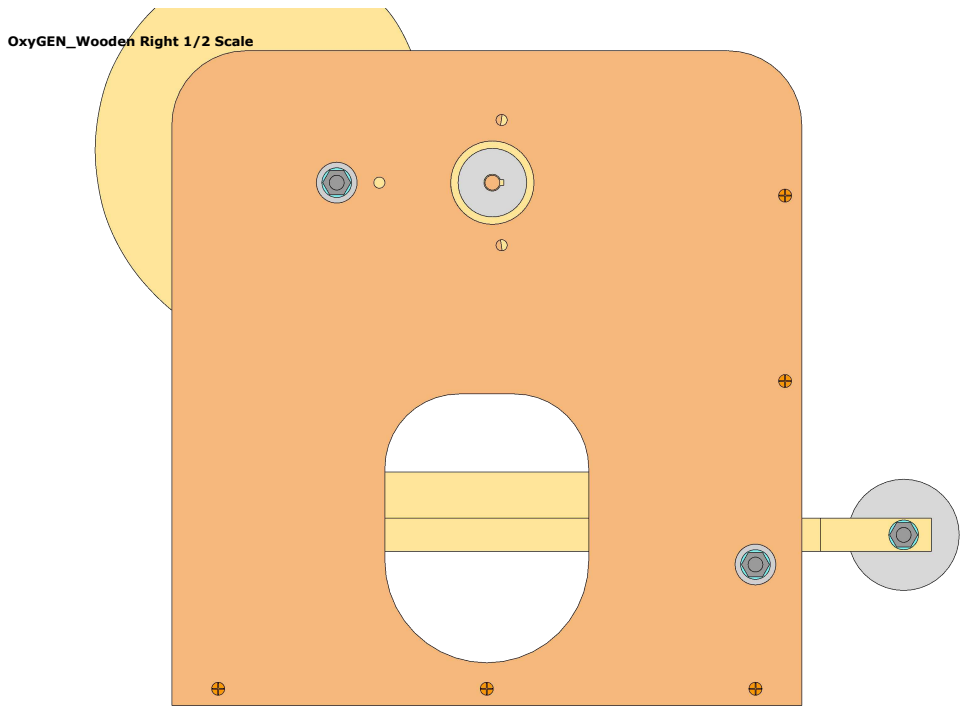
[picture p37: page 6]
OxyGEN_Wooden Right 1/2 Scale

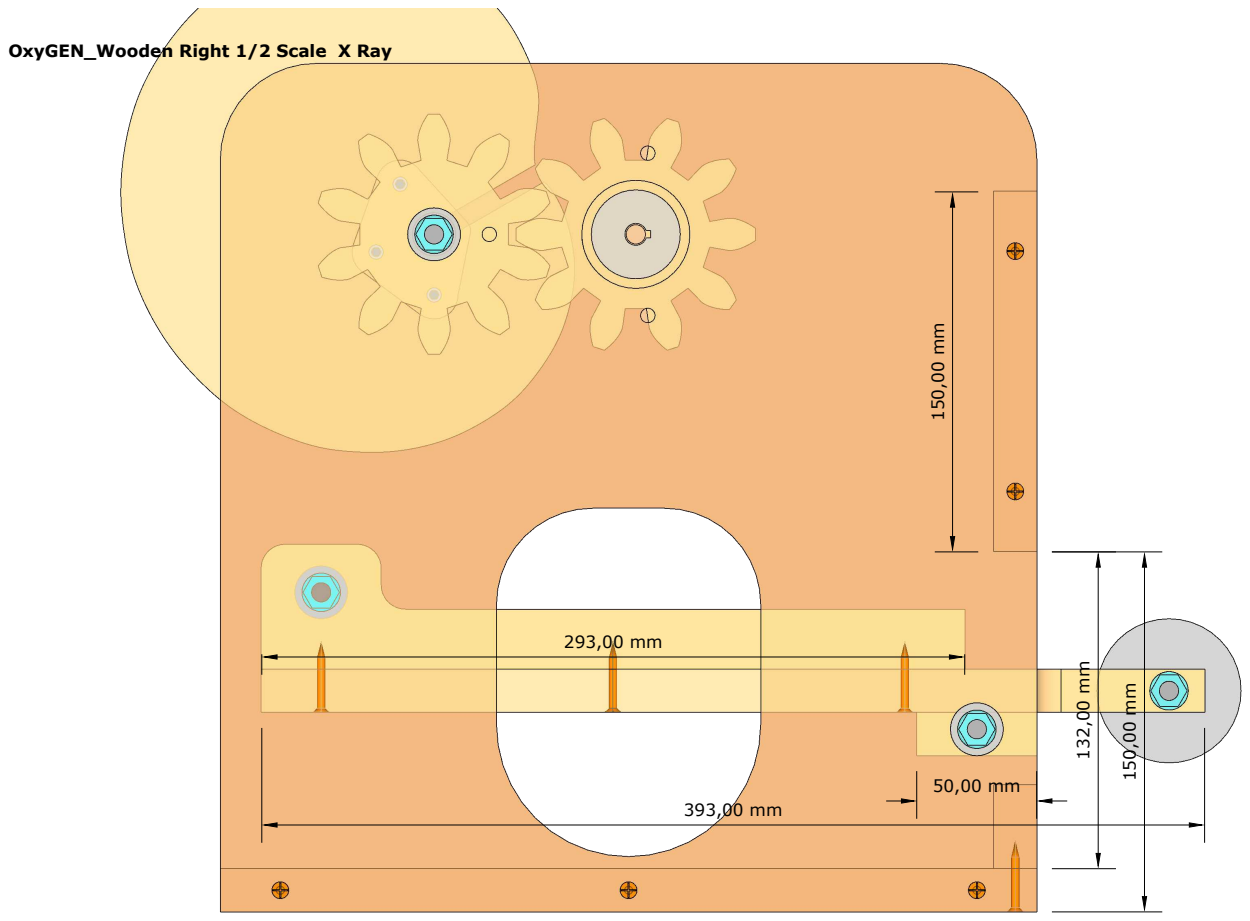
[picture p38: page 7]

OxyGEN_Wooden Right 1/2 Scale X Ray

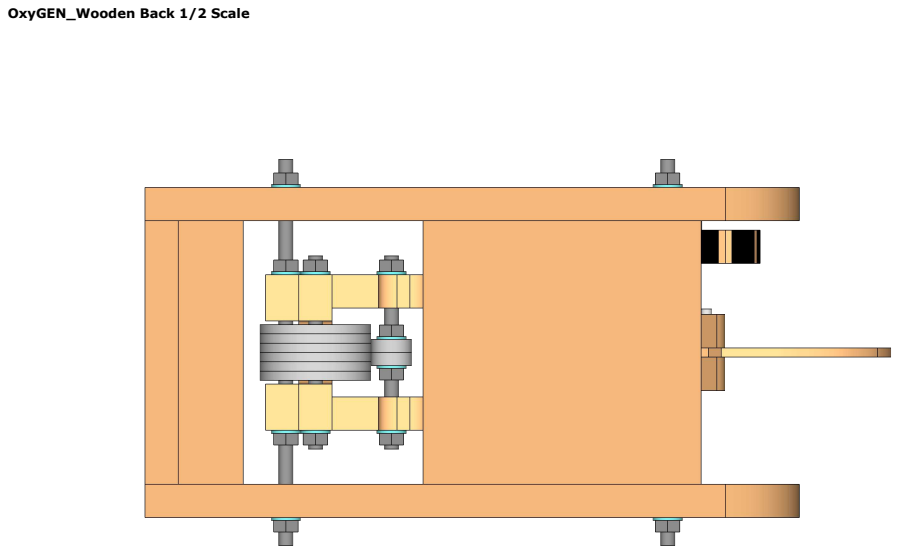
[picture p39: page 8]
OxyGEN_Wooden Back 1/2 Scale

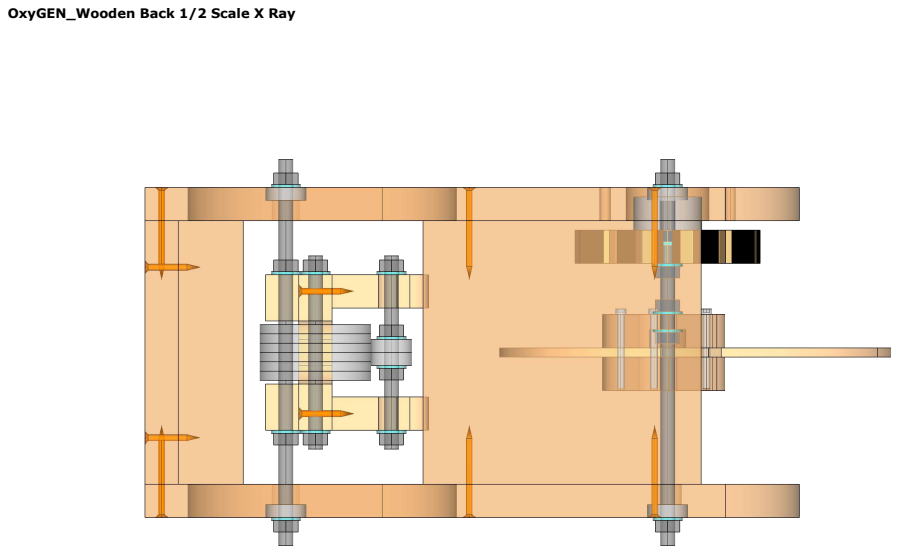
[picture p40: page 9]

OxyGEN_Wooden Back 1/2 Scale X Ray

OxyGEN_Wooden ISO Exploded

OxyGEN_Wooden ISO Exploded 2

OxyGEN_Wooden ISO Exploded 3; M8 Locking Nut; M8 Washer; M8 Threaded Rod

OxyGEN_Wooden ISO Exploded 4; M8 Locking Nut; M4 Allen Socket Head Bolt

OxyGEN_Wooden ISO Exploded 5; 608 Bearing; M8 Locking Nut; 4x50 Wood Screw; ax30 Wood Screw

OxyGEN_Wooden ISO Exploded 6; M8 Threaded Rod; M8 Locking Nut
